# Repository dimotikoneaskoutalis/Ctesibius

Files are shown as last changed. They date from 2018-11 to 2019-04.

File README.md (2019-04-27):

# [Η ΠΡΟΟΔΟΣ ΜΑΣ ΕΔΩ](υλοποίηση.md)

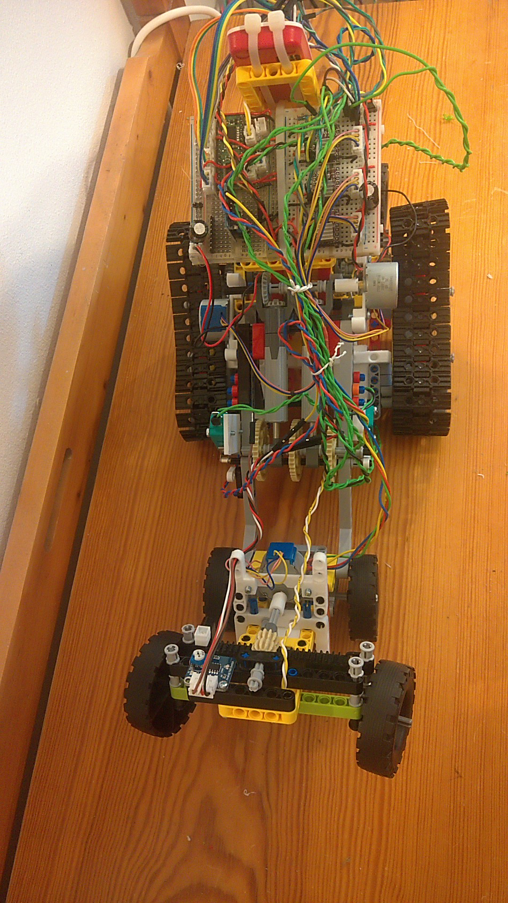
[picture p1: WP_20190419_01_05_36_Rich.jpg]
Τελικό όχημα


# Ctesibius
Ο Κτησίβιος ο Αλεξανδρεύς (285-222 π.Χ.) ήταν μεγάλος μαθηματικός, μηχανικός και εφευρέτης της αρχαίας Ελλάδας, λογιζόμενος κατά ιδιοφυΐα μετά τον Αρχιμήδη. Τα έργα του αφορούσαν τους τομείς των Πνευματικών, των Υδραυλικών και της Στρατιωτικής μηχανικής. Μεταξύ αυτών, η πρώτη πιεστική μηχανή που έφερε δύο έμβολα (πιστόνια) με δυνατότητα παροχής 105 λίτρα/λεπτό.

Οι εφευρέσεις του Κτησίβιου στην Υδραυλική μας δίνουν τη δυνατότητα να εκτοξεύουμε νερό σε μεγάλη απόσταση. Έτσι, οι πυρσοβέστες μπορούν να βρίσκονται μακριά από τις φλόγες. Για ακόμη περισσότερη ασφάλεια, μπορούμε να φτιάξουμε τεχνητούς πυροσβέστες που θα κυκλοφορούν στα δάση και θα σβήνουν έγκαιρα τις πυρκαγιές.

Η εργασία μας αυτή, γίνεται για να τιμήσουμε τη μνήμη των ανθρώπων που χάθηκαν και χάνονται κάθε καλοκαίρι στις δασικές πυρκαγιές.

## Πυροσβέστης
Στα πλαίσια του έργου μας για τον 1ο Πανελλήνιο Διαγωνισμό Ρομποτικής, θα κατασκευάσουμε πυροσβστικό όχημα με πτυσσόμενο μηχανισμό εκτόξευσης νερού. Θα χρησιμοποιηθεί για τον έλεγχό του το Raspberry Pi 3 ή το Raspberry Pi Zero W.

Η ανάπτυξη του οχήματος θα γίνει σε 5 φάσεις:

1. Κινούμενο όχημα
2. Έλεγχος από υπολογιστή
3. Πτυσσόμενη μηχανή κατάσβεσης
4. Κίνηση με προορισμό
5. Κέντρο επιχειρήσεων

Με το τέλος μιας φάσης, θα αρχίζει η επόμενη, ενώ παράλληλα θα βελτιώνουμε ό,τι έχουμε φτιάξει μέχρι τότε.

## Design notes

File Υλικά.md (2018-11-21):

# Υλικά
## LEGO
1. Technic beams σε διάφορα μεγέθη (και γωνίες)
2. Pins
2. Γρανάζια
3. Άξονες
3. Στοπ για άξονες

## Ηλεκτρονικά
1. Raspberry Pi 3
2. Raspberry Pi Zero W
2. Κινητήρες από παιχνίδια
3. Λαμπάκια LED
4. Οδηγοί κινητήρων
5. Μπαταρίες
6. Καλώδια
7. Αντλία νερού

## Παρελκόμενα
1. Σωληνάκια
2. Αντάπτορες LEGO σε οτιδήποτε άλλο (3D Print)
3. Υπολογιστής για το Scratch
4. Υλικά Διακόσμησης

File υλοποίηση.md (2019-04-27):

# Σχεδίαση

Σχεδιάσαμε το όχημα να μετατρέπεται από ερπύστριες σε ρόδες, ανάλογα με το έδαφος.

# Πώς το φτιάξαμε
Δημιουργήσαμε δύο ομάδες. Η μία ομάδα έφτιαξε το μισό όχημα με τις ερπύστριες, ενώ η άλλη έφτιαξε το άλλο μισό με τις ρόδες.

Για το τμήμα με τις ρόδες, φιάξαμε ένα διαφορικό σύστημα μετάδοσης με το κλασικό γρανάζι του LEGO, αφού το κόψαμε για να στηρίξουμε καλύτερα τους άξονες. Την κίνηση στο διαφορικό δίνει κινητήρας με πλανητικό κιβώτιο γραναζιών.

Επίσης φτιάξαμε σύστημα διεύθυνσης με οδηγίες που βρήκαμε στο διαδίκτυο. Την κίνηση στο σύστημα διεύθυνσης δίνει ένας βηματικός κινητήρας.

Για το τμήμα με τις ερπύστριες, βάλαμε δύο διαφορικά συστήματα μετάδοσης κίνησης, ένα για κάθε μεριά του οχήματος. Όταν κινούνται μαζί, το όχημα πηγαίνει ίσια, ενώ όταν κινούνται ανάποδα, το όχημα στρίβει.

Για να ενώσουμε τα δύο τμήματα βάλαμε έναν βηματικό κινητήρα που γυρίζει ένα σύστημα γραμμικής κίνησης. Αυτό κουνάει ένα έκκεντρο γρανάζι, το οποίο σηκώνει το τμήμα με τις ρόδες. Επειδή το όχημα έπεφτε, βάλαμε και μπροστά έναν βηματικό κινητήρα να κατεβάζει δύο ακόμα ρόδες, για να είναι οι ερπύστριες στον αέρα.

Οι βηματικοί κινητήρες έχουν διακόπτες για να σταματάνε όταν φτάσουν στο τέλος της μεταμόρφωσης.
 
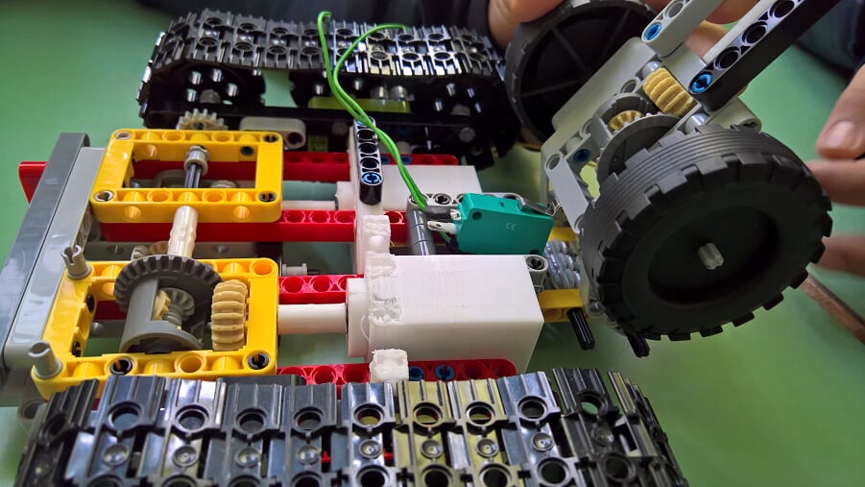
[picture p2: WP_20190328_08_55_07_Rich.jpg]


 # Ηλεκτρονικά
 
 Για να ελέγχουμε το όχημα, χρησιμοποιήσαμε ένα Raspberry Pi Zero W. Ο δάσκαλός μας έχει φτιάξει τις συνδέσεις και μια εφαρμογή για να συνδέεται το Raspberry Pi με το καινούριο scratch (Scratch 3.0), όπου βάζουμε τις εντολές.
 
 Οι εφαρμογές είναι εδώ:
 1. https://github.com/larjohn/scratch-vm
 2. https://github.com/larjohn/hello-pie
 
 Τους βηματικούς κινητήρες τους ελέγχουμε με το DRV8825 και τους κανονικούς με το TB6612FNG.
 
 Για να στερεώσουμε τους κινητήρες φτιάξαμε κι εκτυπώσαμε σε πλαστικό τρισδιάστατες θήκες και αντάπτορες.

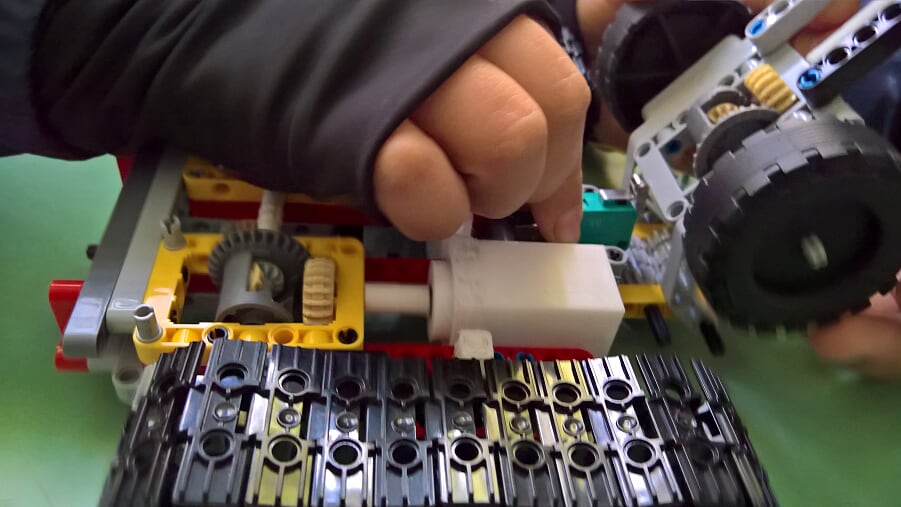
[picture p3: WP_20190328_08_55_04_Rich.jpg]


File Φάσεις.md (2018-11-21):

# Φάσεις Ανάπτυξης Πυροσβεστικού Οχήματος
## 1. Κινούμενο όχημα
Θα κατασκευάσουμε ένα αυτοκίνητο από LEGO, με μηχανισμούς Technic. Θα κινείται με κινητήρα που θα μεταδίδει κίνηση σε δύο ερπίστριες.
## 2. Έλεγχος από υπολογιστή
Θα συνδέσουμε τον κινητήρα του κινούμενου οχήματος με το Raspberry Pi και θα το οδηγούμε μέσα από το Scratch 3. 
## 3. Πτυσσόμενη μηχανή κατάσβεσης
Το όχημα θα αναπτύσσεται προς τα επάνω με χρήση ενός δεύτερου κινητήρα. Στο πάνω μέρος του μηχανισμού θα υπάρχει εκτοξευτής νερού που θα εκτοξεύει νερό.
## 4. Κίνηση με προορισμό
Το όχημα θα έχει πάνω του ένα ενδεικτικό λαμπάκι που θα μας βοηθάει να εντοπίσουμε τη θέση του από το Scratch, με τη χρήση κάμερας που θα το βλέπει από πάνω. Θα στέλνουμε το όχημα σε συγκεκριμένο σημείο.
## 5. Κέντρο επιχειρήσεων
Το κέντρο επιχειρήσεων θα το φτιάξουμε στο Scratch. Θα κάνουμε προσομοίωση μιας πυρκαγιάς και στέλνουμε το όχημα εκεί που πρέπει για να σβήσει γρήγορα η φωτιά και να μην καούν άλλα δέντρα.

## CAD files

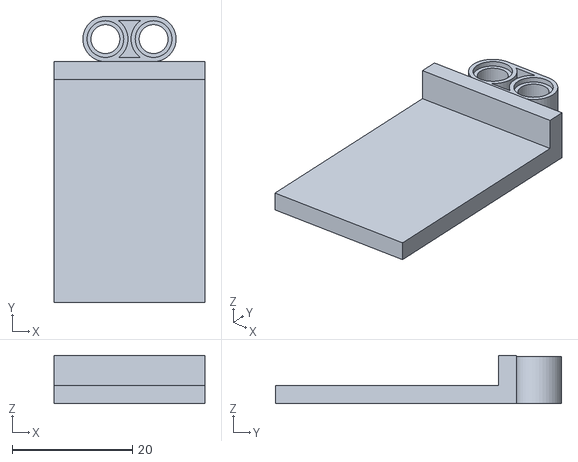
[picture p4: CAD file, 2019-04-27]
3d/Beam2.stl
25.0 x 47.5 x 8.00

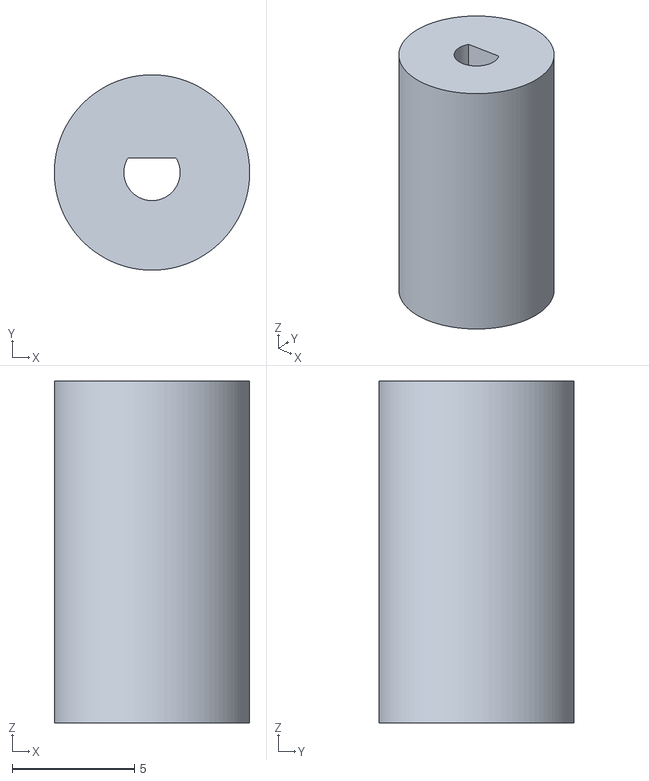
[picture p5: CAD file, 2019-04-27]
3d/my motor coupler3.stl
8.00 x 8.00 x 14.0

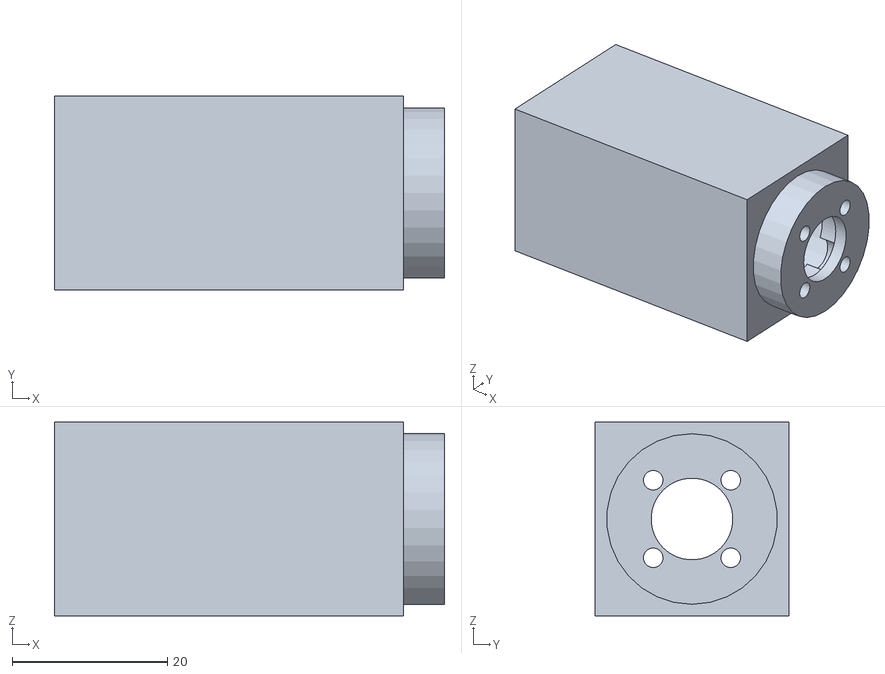
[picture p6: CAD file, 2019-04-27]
3d/Motor Mount.stl
50.3 x 25.0 x 25.0

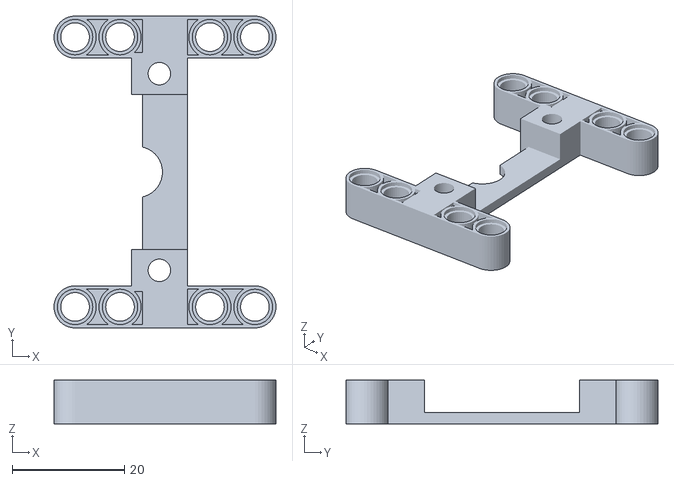
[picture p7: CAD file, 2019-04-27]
3d/uploads_42_72_c5_90_69_Beam.stl
39.5 x 55.5 x 7.80

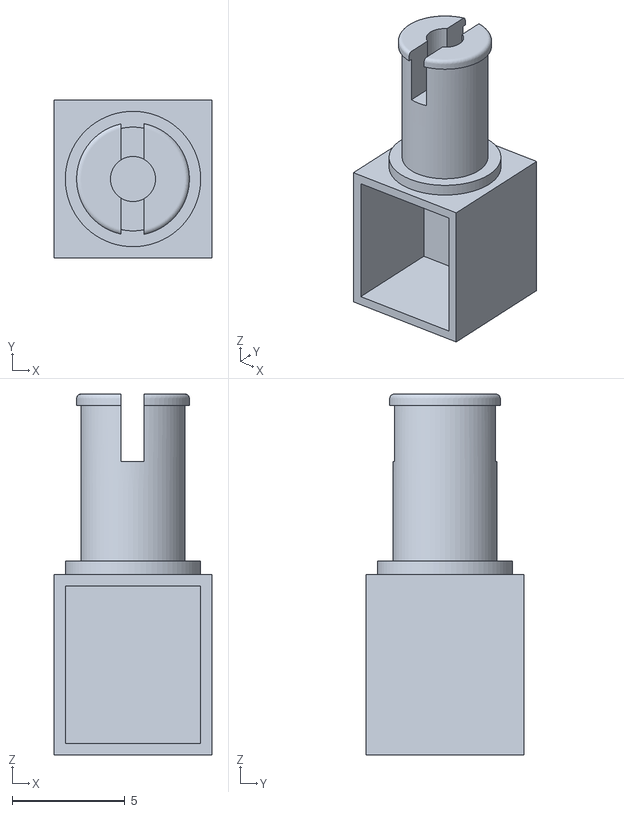
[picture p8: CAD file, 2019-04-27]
3d/magnet case.stl
7.00 x 7.00 x 16.0

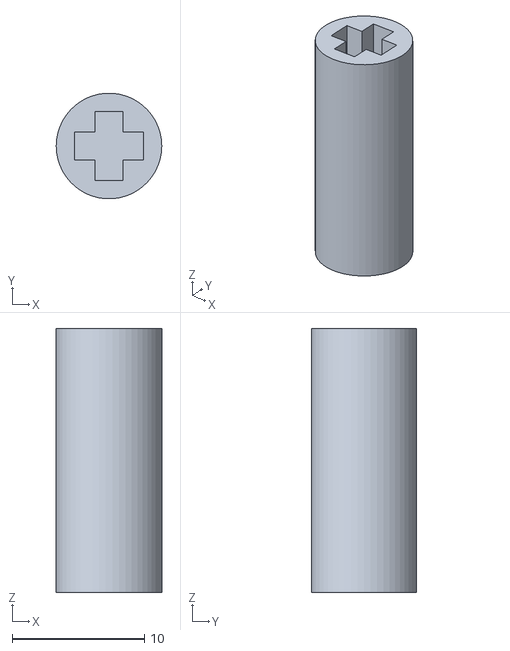
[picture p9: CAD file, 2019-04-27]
3d/alt_motor_coupling.stl
8.00 x 7.98 x 20.0

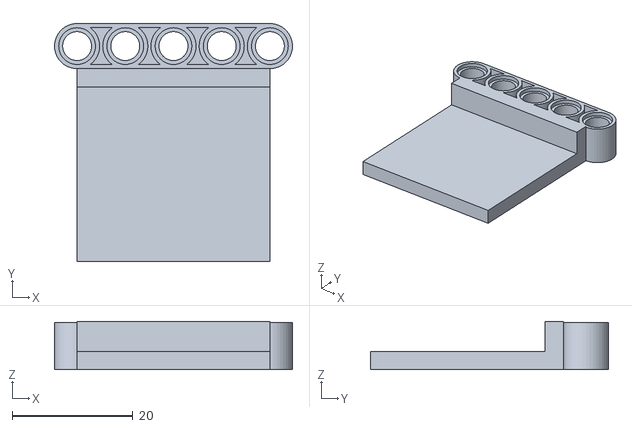
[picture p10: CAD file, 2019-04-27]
3d/Beam3.stl
39.5 x 39.5 x 8.00

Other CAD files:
3d/Beam.stl
